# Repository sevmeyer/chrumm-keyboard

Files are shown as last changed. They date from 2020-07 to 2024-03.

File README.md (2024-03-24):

Chrumm keyboard
===============

Chrumm is an open-hardware ergonomic keyboard,
made of a 3D-printable body, a bendable PCB,
and custom firmware for the Raspberry Pi Pico.

This repository contains all relevant source files.
I share these files in the hope that they are useful, or
at least interesting to others. Keep in mind that this is
a free, do-it-yourself project. What you see is what you get.
Make sure to check the license.

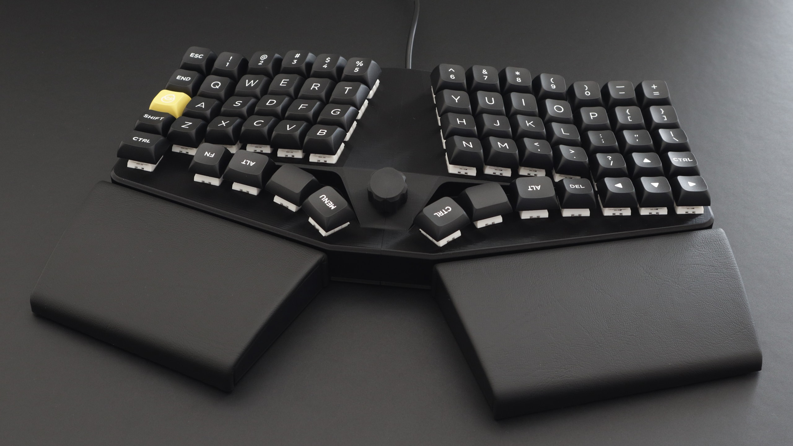
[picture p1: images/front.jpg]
Front view of the finished keyboard


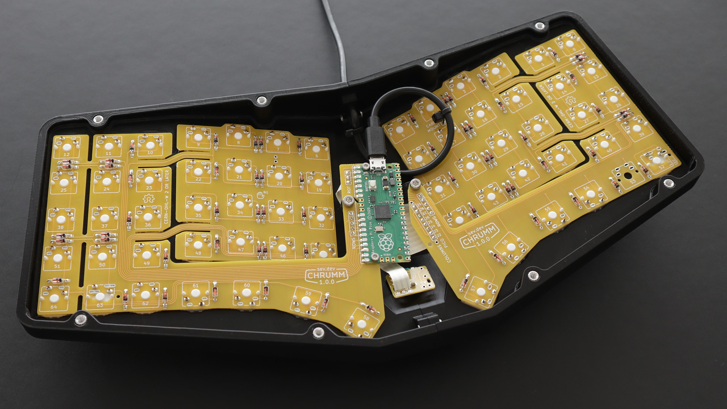
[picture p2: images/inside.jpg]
Inside view with installed electronics


Files
-----

- [Releases] - Download page for STL, 3MF, GBR, UF2 files
- [BUILD.md](BUILD.md) - Build advice
- [MATERIALS.md](MATERIALS.md) - Bill Of Materials
- [pcb/README.md](pcb/README.md) - PCB production details
- [body/README.md](body/README.md) - Body generator parameters
- [firmware/README.md](firmware/README.md) - Firmware overview and installation

[Releases]: https://github.com/sevmeyer/chrumm-keyboard/releases/

Features
--------

Chrumm features a column staggered layout with simple thumb clusters.
The right side has an additional column, to better approximate
the standard ANSI layout, and to provide dedicated arrow keys.
A central encoder allows for rotational input.

The body is a robust monoblock without visible screws. It has
integrated split, tent, and tilt angles, similar to commercial
ergonomic boards. The palm rests and the USB cable are firmly
attached, so that everything can be moved around without hassle.

The STL files are generated programmatically, with a pure
Python package that has no dependencies. They are optimized
for FFF 3D printing. Most parts are printed sideways, to
produce a smooth surface without the need of post-processing.
Custom supports minimize the print time and filament cost.

The body houses two reversible, bendable, interconnected PCBs.
They are powered by a Raspberry Pi Pico.

Layout
------

Default logical layout with two layers

Credit
------

Chrumm would not exist without the shared knowledge of the
mechanical keyboard community.

I found inspiration on [Reddit], [KBD.news], [geekhack], and
learned a lot from the [PCB guides] by ai03 and Ruiqi Mao, the
[Keyboard posts] by Masterzen, and the [Matrix Help] by Dave Dribin.

The layout and body is influenced by projects like the [Ergodox],
[Dactyl], [Sofle], [Pteron], and everything from [Bastardkb].
I also used established open hardware repositories for reference,
including the [UHK60], [Skeletyl], [Sofle], [Corne], and [Torn].

[Reddit]: https://old.reddit.com/r/ErgoMechKeyboards+MechanicalKeyboards/
[KBD.news]: https://kbd.news/
[geekhack]: https://geekhack.org
[PCB guides]: https://wiki.ai03.com/books/pcb-design
[Keyboard posts]: https://www.masterzen.fr/tag/#mechanical-keyboards
[Matrix Help]: https://www.dribin.org/dave/keyboard/one_html/
[Ergodox]: https://www.ergodox.io/
[Dactyl]: https://github.com/adereth/dactyl-keyboard
[Sofle]: https://github.com/josefadamcik/SofleKeyboard
[Pteron]: https://github.com/FSund/pteron-keyboard
[Bastardkb]: https://bastardkb.com/
[UHK60]: https://github.com/UltimateHackingKeyboard/uhk60v1-electronics
[Skeletyl]: https://github.com/Bastardkb/Skeletyl-PCB-plate
[Corne]: https://github.com/foostan/crkbd
[Torn]: https://github.com/rtitmuss/torn

Gallery
-------

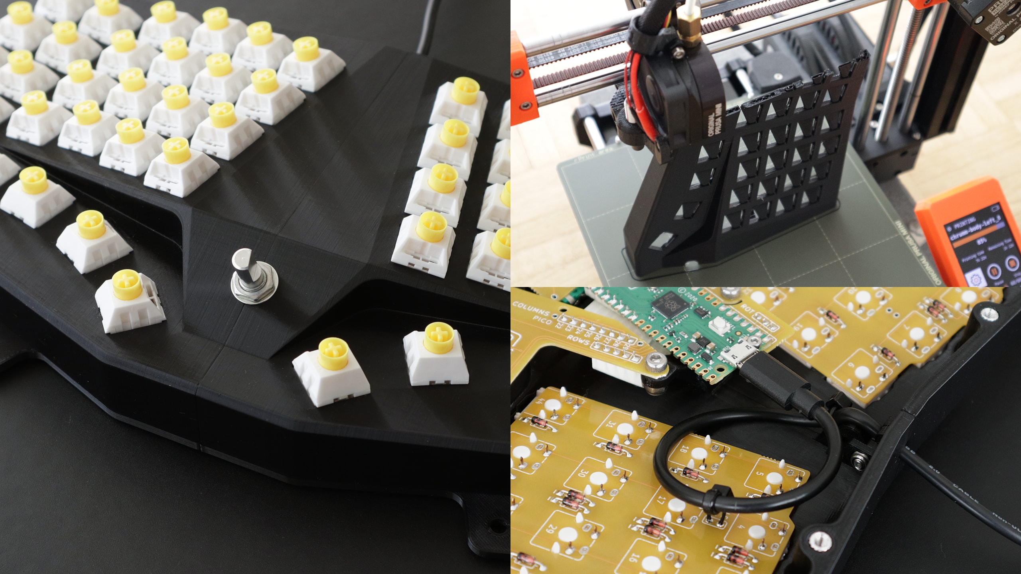
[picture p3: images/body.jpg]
Print and assembly of the body


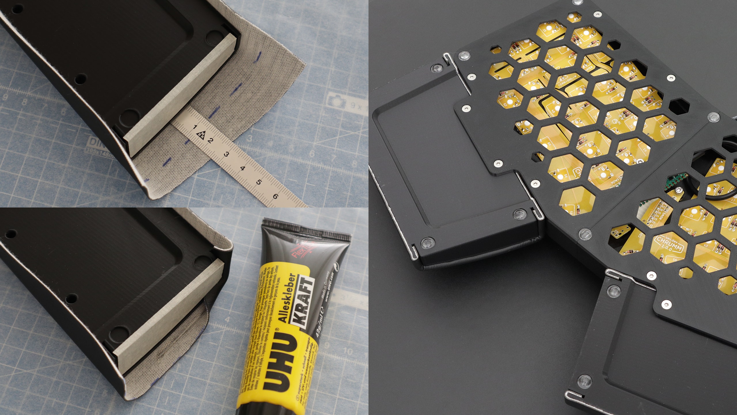
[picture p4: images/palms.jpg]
Palm rests wrapped with artificial leather


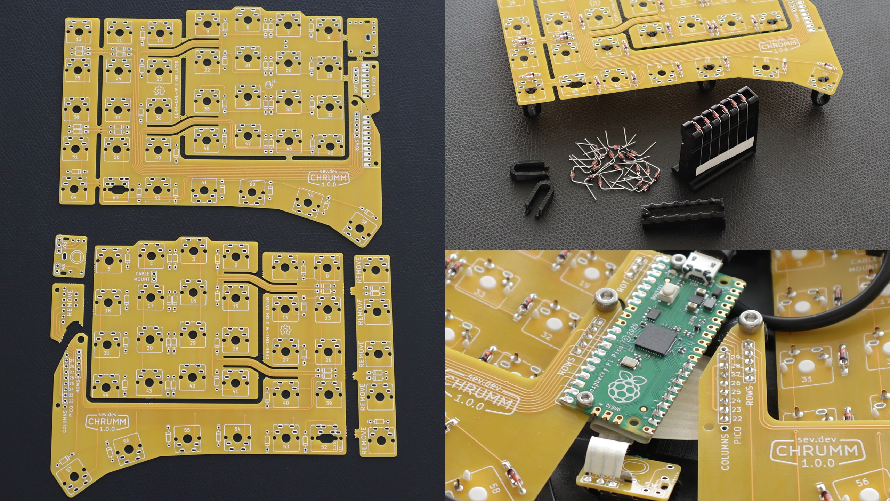
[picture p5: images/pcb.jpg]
Preparation and installation of the PCB


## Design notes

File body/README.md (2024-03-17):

Chrumm STL generator
====================

The STL files are generated with the `chrumm` package for Python 3.7+.
It has no dependencies and does not need to be compiled or installed.
Run it as a command-line tool from this directory:

    python3 -m chrumm --help

To generate the default STL files:

    python3 -m chrumm chrumm.json

Parameters
----------

The configuration parameters are provided via JSON files.
If a parameter appears multiple times, then its latest value
is used. Distances are given in millimeters, angles in degrees.

#### PCB compatibility

Unlike the body, the PCB is manually edited and not programmatic.
Changes to the body parameters may not be compatible with the PCB.
A flattened KiCad footprint (.kicad_mod) is generated to help with
the placement of the switches and screws on the PCB.

#### Parameter validation

The generator does not validate all of the parameters.
Most importantly, chamfers and switch notches are not
taken into account when placing the walls. Make sure
that the switch margin parameter provides enough room.

The generator should produce reasonable results for
split, tent, and tilt angles up to about 20 degrees.
Results may vary for more extreme angles.

#### Layout

The `layout.fingerStaggers` matrix represents the
offset of each key relative to its ortholinear position.

The matrix is a list of rows. Each row contains four
sublists, to represent the sections of the keyboard
(left pinky, left alnum, right alnum, right pinky).
Each section contains key offset coordinates.
A coordinate can be an empty list (key omitted), a single
number (y offset), or a list of two numbers (x and y offset).

Each section must have at least two key coordinates.
All rows must have the same column structure.

#### Omit items

Chamfers can be turned off by setting them to `0`.
The value of the following parameters can be set
to `false` in order to omit them from the output:

    bracket
    bumper
    cable
    encoder
    floor.hexHoles
    knob
    palm
    pcb
    pcb.mount
    support
    switch.clipNotch

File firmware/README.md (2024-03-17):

Chrumm firmware
===============

The firmware is written in C for the [Raspberry Pi Pico].
If you instead prefer a more standard toolkit, check out
the experimental [QMK config] for Chrumm.

[Raspberry Pi Pico]: https://www.raspberrypi.com/products/raspberry-pi-pico/
[QMK config]: https://github.com/sevmeyer/chrumm-qmk

Features
--------

The firmware implements two [USB HID] interfaces. Interface 0 acts
as a standard Boot Keyboard. Interface 1 sends HID Consumer codes
for application-specific controls, including multimedia.

Two layers are available. Hold down the `Fn` key to momentarily
activate the alternative layer. Double tap `Fn` to stay on the
alternative layer until `Fn` is tapped again.

Optionally, the rotation signals of an EC11 encoder can be
mapped to virtual key presses.

The special `kBOOT` keycode (Fn+Z) can be tapped three times
to put the keyboard into bootloader mode without the need to
unplug the USB cable.

For debugging purposes, the on-board LED of the Pico indicates
non-default lock states. When Caps Lock is on, the LED is on.
When Num Lock is off, the LED blinks once every 2 seconds.

[USB HID]: https://www.usb.org/document-library/device-class-definition-hid-111

Compile
-------

The default UF2 binary is available on the [Releases] page.

To compile a custom version, install the [Pico SDK] and [Arm GNU Toolchain].
Set the `PICO_SDK_PATH` environment variable to the SDK directory.
Append the Arm `bin` directory to the `PATH` environment variable.
The firmware can then be prepared and compiled with:

    cmake -B build
    cmake --build build

[Releases]: https://github.com/sevmeyer/chrumm-keyboard/releases
[Pico SDK]: https://github.com/raspberrypi/pico-sdk
[Arm GNU Toolchain]: https://developer.arm.com/Tools%20and%20Software/GNU%20Toolchain

Install
-------

Hold down the `BOOTSEL` button on the Pico while plugging in
the USB cable. It should show up as a USB storage device.
After the first install, you can keep the keyboard plugged in
and instead tap Fn+Z three times.

Drag-and-drop the UF2 binary from the build directory onto the device.
The Pico should automatically restart and run the firmware.
Alternatively, install [picotool] and use:

    picotool load build/chrumm.uf2 --force
    picotool reboot

[picotool]: https://github.com/raspberrypi/picotool

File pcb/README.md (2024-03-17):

Chrumm PCB
==========

The PCB is made with [KiCad], version 7.

The PCB is reversible. It covers half of the keyboard,
and is flipped over for the other half. It is intended
to slightly bend between the pinky and ring finger,
therefore the board thickness should not exceed 0.8mm.

All connections are through-hole (or castelated), so
that they can be soldered with basic hobby equipment.
The switch pin holes are implemented as slots, to
provide a snug fit for the flat pins, and thus
minimize the required amount of solder.

[KiCad]: https://www.kicad.org/

Teardrops
---------

The teardrops are generated with a custom [KiCad plugin],
using the following settings:

    PTH arc radius: 250%
    SMD arc radius: 250%
    Via arc radius: 350%

[KiCad plugin]: https://github.com/sevmeyer/kicad-arc-teardrops

Production
----------

I ordered the prototypes from [PCBWay] (no affiliation).
Other manufacturers are available, check for example
[PCBShopper] or [Manufacturing Reports]. Here are some of
the relevant specifications, use them at your own discretion:

- Standard PCB (not flex)
- Single pieces (not panelized)
- Layers: 2
- Material: FR4 TG 150-160
- Thickness: 0.8mm (at most)
- Surface finish: HASL (lead free)
- Copper thickness: 1oz

[PCBWay]: https://pcbway.com/
[PCBShopper]: https://pcbshopper.com/
[Manufacturing Reports]: https://manufacturingreports.com/category/electronics/rigid-pcb-fabrication/

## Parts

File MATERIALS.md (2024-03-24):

Chrumm Bill Of Materials
========================

Mechanical
----------

- 12x Threaded insert, M3, 4mm hole diameter, max 5.7mm length
- 12x Countersunk screw, M3, 8mm total length, ISO 10642
-  7x Hex nut with nylon insert, M3, ISO 10511
-  2x Hex nut with nylon insert, M2
-  7x Socket head cap screw, M3, 8mm thread length, ISO 4762 (*)
-  2x Socket head cap screw, M2, 6mm thread length, ISO 4762
-  2x Ziptie, 2mm width, 1mm thickness
- 14x 3M Bumpon SJ5302, hemispherical, 8mm diameter, 2mm height
-  2x Artificial leather, ~190x130mm, max 1.2mm thickness
- Glue for artificial leather on printed filament
- Keycaps (in photo: Akko WOB Building Blocks, MDA profile)

(*) Some of the screws are difficult to reach and
require a ball-point driver, or a short-armed key.

Electronic
----------

-  2x PCB
-  1x Raspberry Pi Pico, SC0915, without pre-soldered headers
-  1x USB cable, A to micro-B with small head, shielded, max 4mm diameter
- 64x Diode, 1N4148, DO-35 through-hole format
- 64x MX switch
-  1x Bourns PEC11R-4215F-N0024 rotary encoder, M7 nut mount, 15mm flatted D-shaft
-  1x TE Flexstrip FSN-22A-8, 0.1" pitch, 2" length, 8 conductors (**)
-  1x TE Flexstrip FSN-22A-5, 0.1" pitch, 2" length, 5 conductors (**)
-  1x TE Flexstrip FSN-23A-3, 0.1" pitch, 3" length, 3 conductors (**)

(**) It might be cheaper to buy strips with
more conductors and cut them apart as needed.

3D-printed
----------

-  2x Body half (left, right)
-  2x Floor half (left, right)
-  2x Palm rest (left, right)
-  1x Rotary encoder knob
-  1x Diode bender jig, 7.62mm pitch (300mil)
- 12x Diode standoff jig

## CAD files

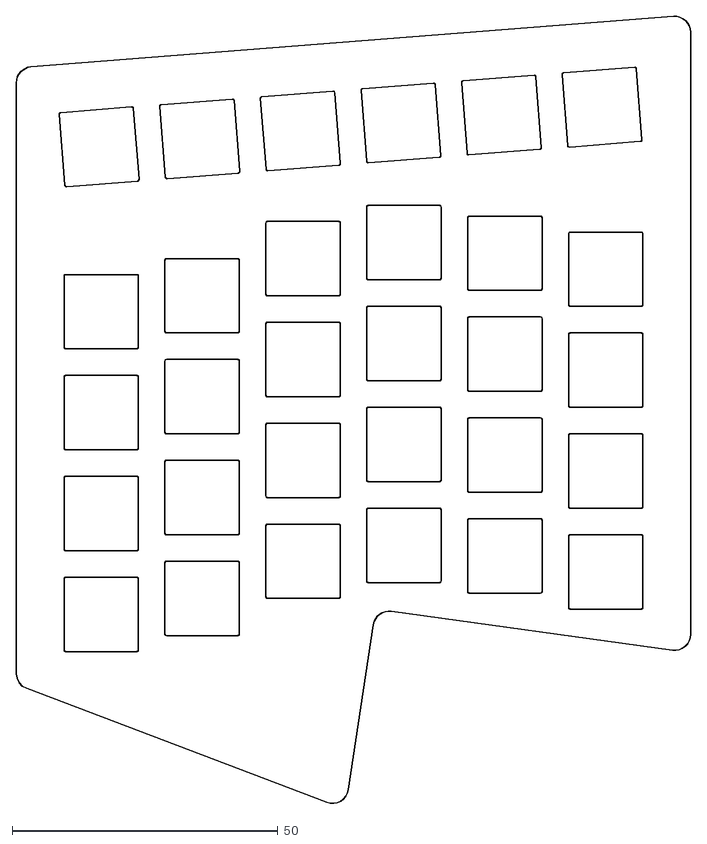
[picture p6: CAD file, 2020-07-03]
files/chrumm-01-plate-left.dxf
127.0 x 148.4

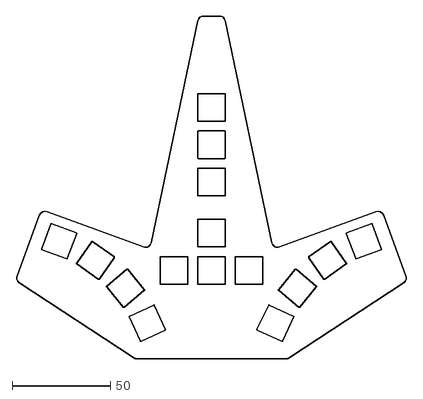
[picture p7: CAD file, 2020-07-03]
files/chrumm-01-plate-middle.dxf
198.9 x 174.5

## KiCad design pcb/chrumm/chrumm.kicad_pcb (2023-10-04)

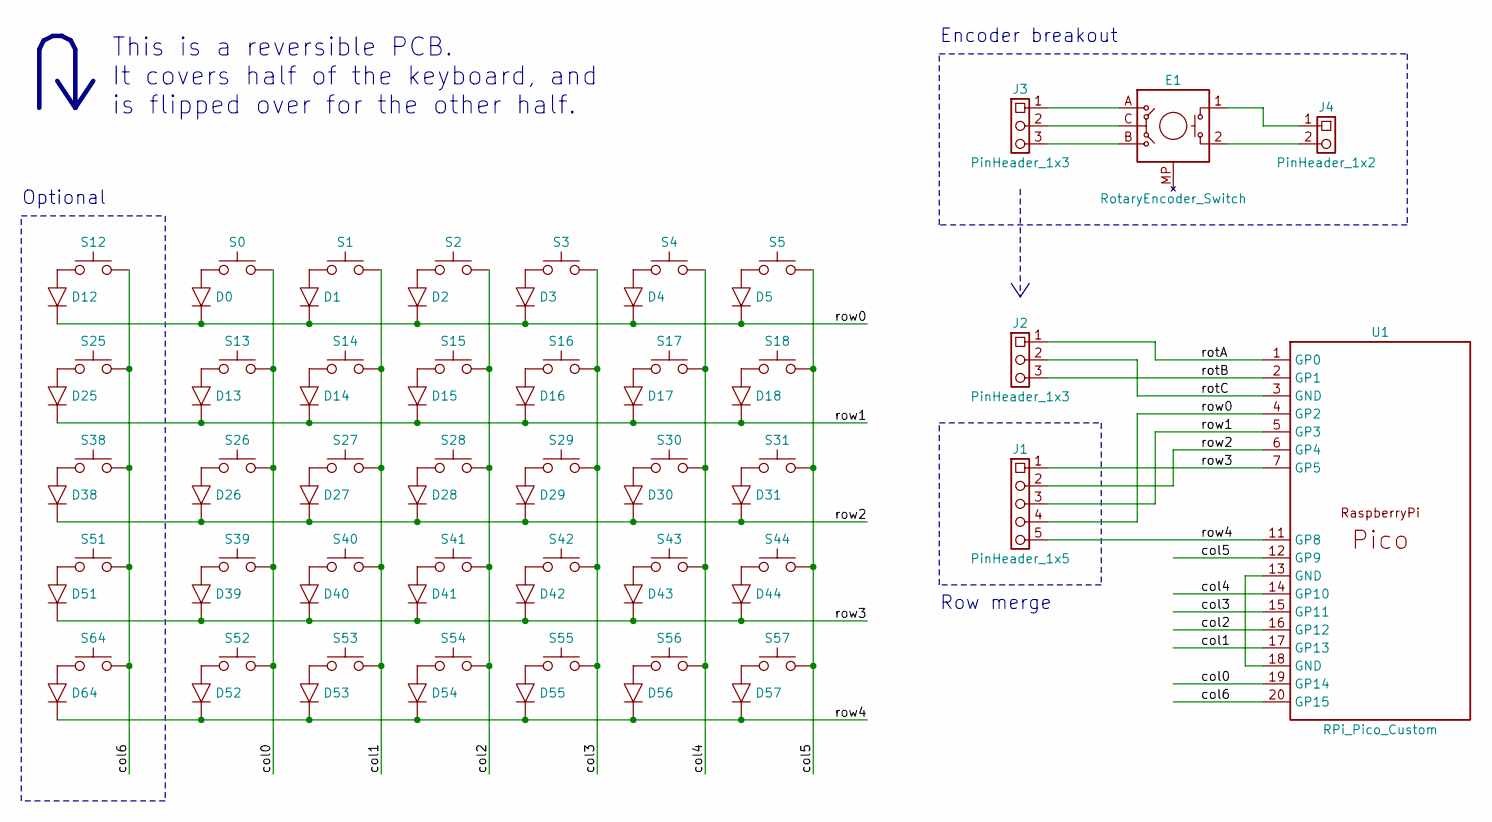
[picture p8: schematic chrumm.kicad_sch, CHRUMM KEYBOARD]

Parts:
D0, D1, D2, D3, D4, D5, D12, D13, D14, D15, D16, D17, D18, D25, D26, D27, D28, D29, D30, D31, D38, D39, D40, D41, D42, D43, D44, D51, D52, D53, D54, D55, D56, D57, D64: Diode
E1: RotaryEncoder_Switch
J1: PinHeader_1x5
J2, J3: PinHeader_1x3
J4: PinHeader_1x2
S0, S1, S2, S3, S4, S5, S12, S13, S14, S15, S16, S17, S18, S25, S26, S27, S28, S29, S30, S31, S38, S39, S40, S41, S42, S43, S44, S51, S52, S53, S54, S55, S56, S57, S64: Switch
U1: RPi_Pico_Custom

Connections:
/col0: S0.1, S13.1, S26.1, S39.1, S52.1, U1.19 (GP14)
/col1: S1.1, S14.1, S27.1, S40.1, S53.1, U1.17 (GP13)
/col2: S2.1, S15.1, S28.1, S41.1, S54.1, U1.16 (GP12)
/col3: S3.1, S16.1, S29.1, S42.1, S55.1, U1.15 (GP11)
/col4: S4.1, S17.1, S30.1, S43.1, S56.1, U1.14 (GP10)
/col5: S5.1, S18.1, S31.1, S44.1, S57.1, U1.12 (GP9)
/col6: S12.1, S25.1, S38.1, S51.1, S64.1, U1.20 (GP15)
/rotA: J2.1, U1.1 (GP0)
/rotB: J2.3, U1.2 (GP1)
/rotC: J2.2, U1.3 (GND)
/row0: D0.1 (K), D1.1 (K), D2.1 (K), D3.1 (K), D4.1 (K), D5.1 (K), D12.1 (K), J1.4, U1.4 (GP2)
/row1: D13.1 (K), D14.1 (K), D15.1 (K), D16.1 (K), D17.1 (K), D18.1 (K), D25.1 (K), J1.3, U1.5 (GP3)
/row2: D26.1 (K), D27.1 (K), D28.1 (K), D29.1 (K), D30.1 (K), D31.1 (K), D38.1 (K), J1.2, U1.6 (GP4)
/row3: D39.1 (K), D40.1 (K), D41.1 (K), D42.1 (K), D43.1 (K), D44.1 (K), D51.1 (K), J1.1, U1.7 (GP5)
/row4: D52.1 (K), D53.1 (K), D54.1 (K), D55.1 (K), D56.1 (K), D57.1 (K), D64.1 (K), J1.5, U1.11 (GP8)
unnamed: D0.2 (A), S0.2
unnamed: D1.2 (A), S1.2
unnamed: D2.2 (A), S2.2
unnamed: D3.2 (A), S3.2
unnamed: D4.2 (A), S4.2
unnamed: D5.2 (A), S5.2
unnamed: D12.2 (A), S12.2
unnamed: D13.2 (A), S13.2
unnamed: D14.2 (A), S14.2
unnamed: D15.2 (A), S15.2
unnamed: D16.2 (A), S16.2
unnamed: D17.2 (A), S17.2
unnamed: D18.2 (A), S18.2
unnamed: D25.2 (A), S25.2
unnamed: D26.2 (A), S26.2
unnamed: D27.2 (A), S27.2
unnamed: D28.2 (A), S28.2
unnamed: D29.2 (A), S29.2
unnamed: D30.2 (A), S30.2
unnamed: D31.2 (A), S31.2
unnamed: D38.2 (A), S38.2
unnamed: D39.2 (A), S39.2
unnamed: D40.2 (A), S40.2
unnamed: D41.2 (A), S41.2
unnamed: D42.2 (A), S42.2
unnamed: D43.2 (A), S43.2
unnamed: D44.2 (A), S44.2
unnamed: D51.2 (A), S51.2
unnamed: D52.2 (A), S52.2
unnamed: D53.2 (A), S53.2
unnamed: D54.2 (A), S54.2
unnamed: D55.2 (A), S55.2
unnamed: D56.2 (A), S56.2
unnamed: D57.2 (A), S57.2
unnamed: D64.2 (A), S64.2
unnamed: E1.1, J4.1
unnamed: E1.2, J4.2
unnamed: E1.A, J3.1
unnamed: E1.B, J3.3
unnamed: E1.C, J3.2
unnamed: U1.13 (GND), U1.18 (GND)

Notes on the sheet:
Encoder breakout
Optional
Row merge
This is a reversible PCB. It covers half of the keyboard, and is flipped over for the other half.

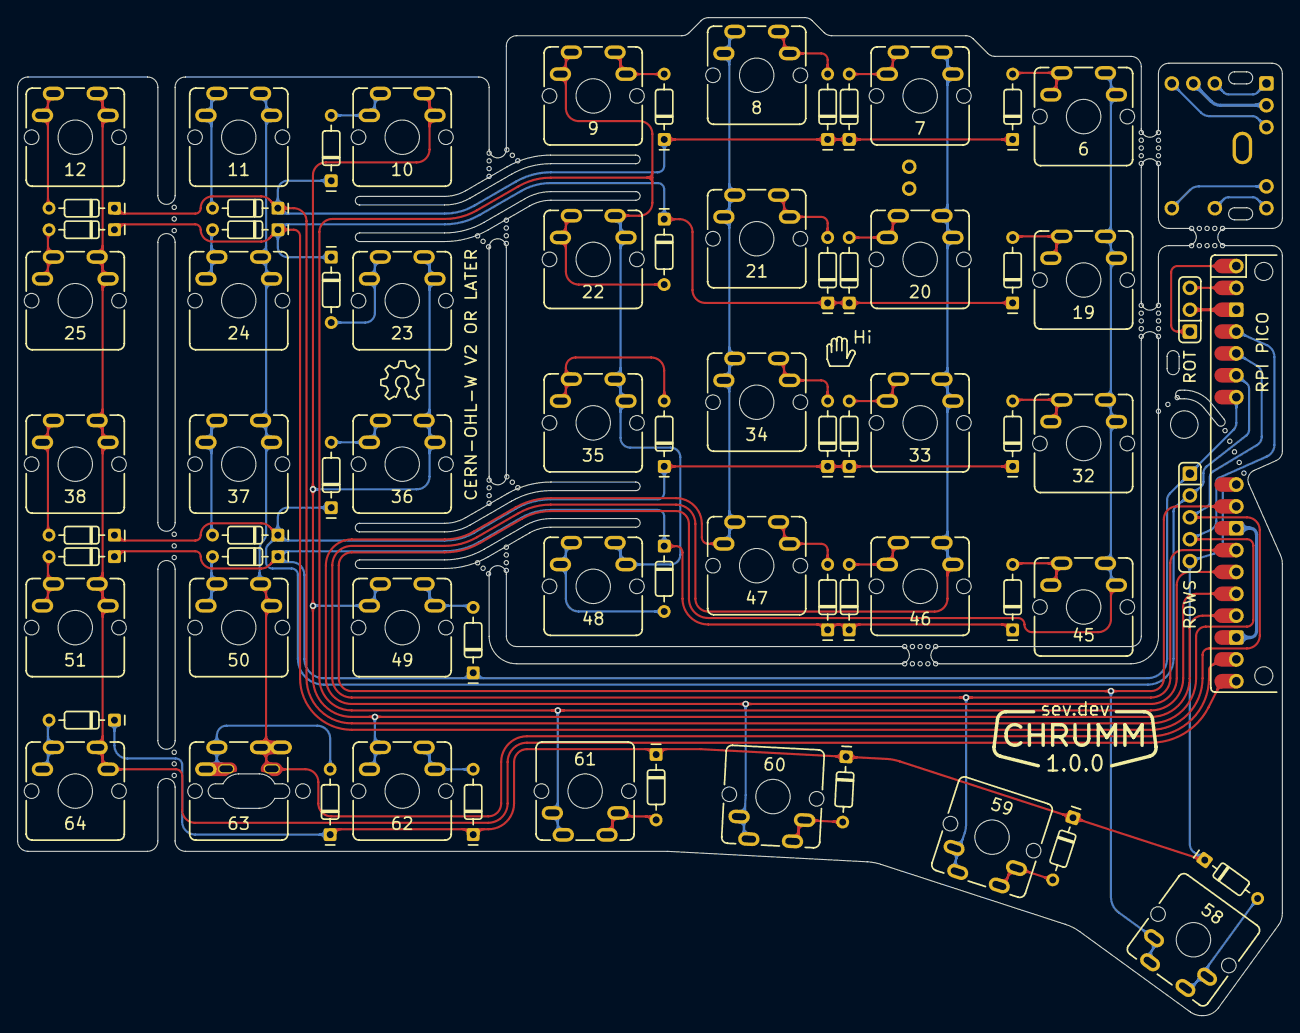
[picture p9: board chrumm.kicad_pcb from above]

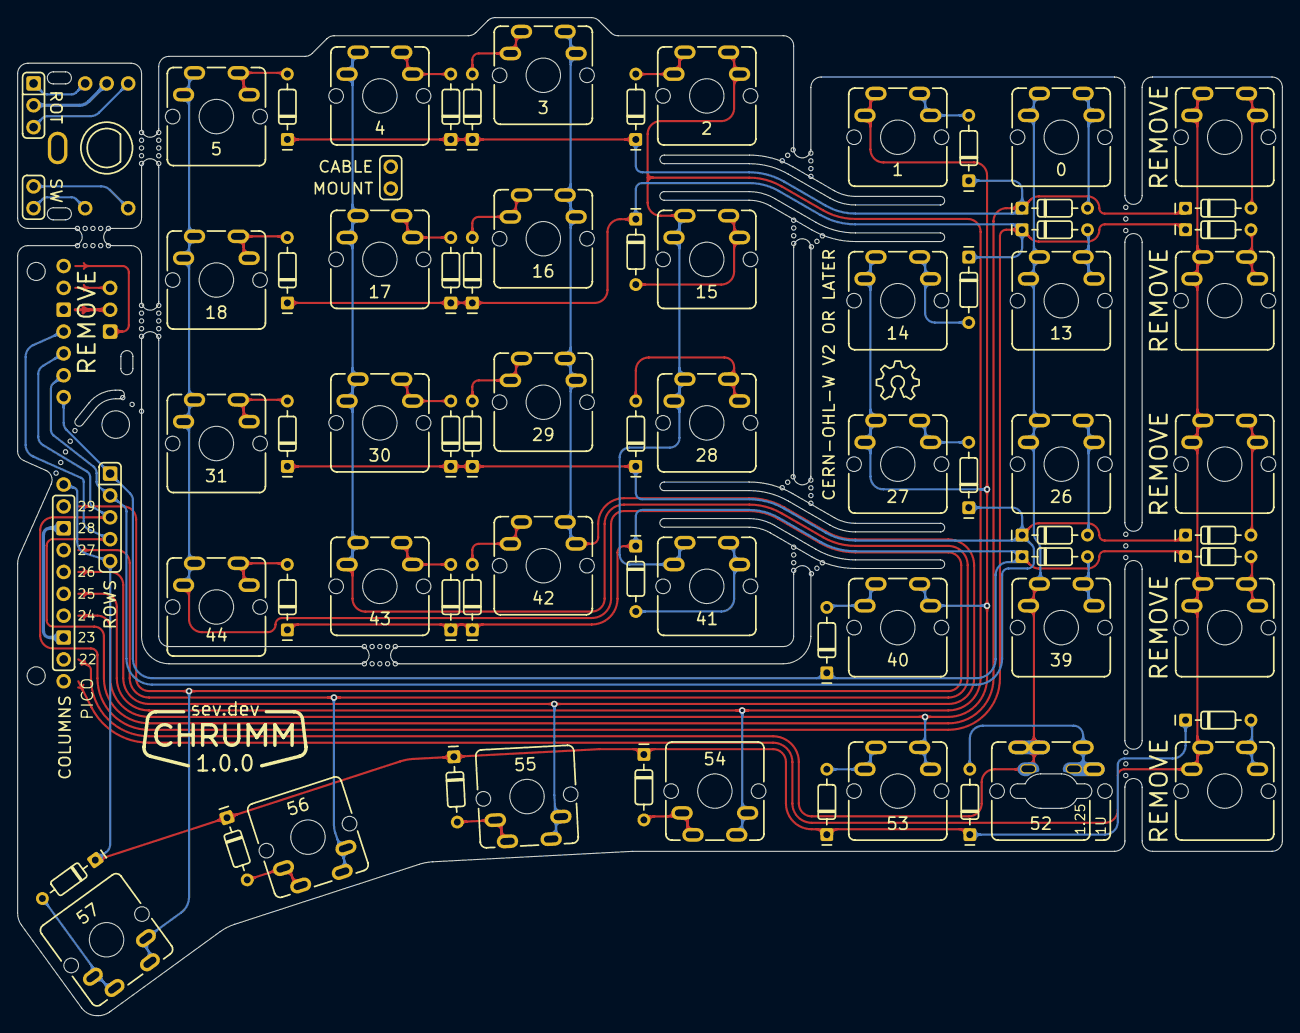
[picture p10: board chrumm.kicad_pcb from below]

Board: 2 copper layers, 147.0 x 116.0 mm, 76 parts (9 on the bottom side), 56 nets.

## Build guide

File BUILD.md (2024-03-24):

Chrumm build advice
===================

Printing
--------

I printed the parts on a Prusa Mini, with PLA filament, on a
smooth PEI sheet. The gcode was generated with [PrusaSlicer] 2.6.0.
The 3MF files with the exact print settings and part configurations
are available on the [Releases] page.

The body halves are printed sideways, with custom supports.
In PrusaSlicer, custom supports can be added in the
[Object list] (Advanced mode). Right-click on the body object
and load the support STL with "Add Part". Right-click on the
support object to adjust its print settings.

[PrusaSlicer]: https://www.prusa3d.com/prusaslicer/
[Object list]: https://help.prusa3d.com/article/object-list_1758
[Releases]: https://github.com/sevmeyer/chrumm-keyboard/releases

Diodes
------

Note that there is not much room between the switch plate and
the PCB. Therefore, I soldered the diode legs on the same side
as the diode body, and cut the legs reasonably short on the
switch-facing side with a [flush cutter]. To hold up the PCB
while soldering the diodes, I used standoff jigs that clip
into the stem holes (see photos).

The diode pads have a common pitch of 7.62mm (300mil).
To bend the legs in a uniform way, I used a bender jig.
Both jigs are available on the [Releases] page.

[flush cutter]: https://en.wikipedia.org/wiki/Diagonal_pliers#Variations

Flexstrip
---------

The PCB halves are connected via Flexstrip jumpers. To compensate
for the default split angle, the strips should be folded in a
specific way before installation. Check the image for reference.
I wrapped the strips around a thin screwdriver shaft, to maintain
a minimum bend radius of about 2mm.

Fold lines for flexstrip jumpers

PCB installation
----------------

To install the PCB, I would first clip the corner switches
into the body, e.g. switches 12-64-58, 10-9-6, and 49-48-45.
Then align the PCB with the switch pins and push it flat
against the switch bottoms.

Before soldering any switches, check that the screw mount
next to the Pico does not bend the PCB. If the print is
misaligned, you might want to sand off a bit of the mount,
or extend its height with a washer.

When everything fits, the remaining switches can be inserted.
Note that the thumb switches are north-facing (upside down).

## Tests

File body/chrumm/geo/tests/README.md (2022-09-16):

Run the tests from the parent directory of the chrumm package:

    python3 -m unittest discover

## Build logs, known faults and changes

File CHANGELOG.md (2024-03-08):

Development
-----------

body 1.0.2
- Add optional parameters for switches with clips on their side
  * switch.clipNotch.isSideways  (Left-right instead of front-back)
  * support.relBasePosition      (Sideways position relative to top)
  * support.relBaseInset         (From switch hole front to back)
  * support.relTopInset          (From switch hole front to back)

body 1.0.1
- Revise Face triangulation for better performance
- Remove obsolete draft.json

firmware 1.0.2
- Use PID 1209:5E7C as registered on pid.codes

firmware 1.0.1
- Add kBOOT keycode to trigger bootloader mode
- Remove cRWND and cFFWD from default layout
- Revise pin settle time and encoder keypress ticks

1.0 (2023-10-04)
----------------

- First release

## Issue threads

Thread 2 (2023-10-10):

Chrumm 36

sahidrahman404, 2023-10-10:
Are there any plans to create a variant of this keyboard with 36 keys?

sevmeyer, 2023-10-10:
I assume you refer to Miryoku. There are no plans to support such small layouts, sorry.

The current construction of the body and PCB assumes at least two pinky columns.
Also, the Pico would not easily fit in its current orientation.
Ultimately, Miryoku would require non-trivial adjustments.

Closed 2023-10-10.

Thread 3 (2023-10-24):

stls

TuneClausen, 2023-10-24:
Hello. I'm in love with the chrumm and have today recieved the pcbs. Could you upload the stls that you have used for your layout? I fear that I'm too stupid to use the python files that you have supplied :)

giovanniborella, 2023-10-24:
Check the releases: https://github.com/sevmeyer/chrumm-keyboard/releases/tag/1.0

sevmeyer, 2023-10-24:
Thanks @giovanniborella.

On the releases page you can also download the 3mf files,
which contain the print settings for [PrusaSlicer] 2.6.

[PrusaSlicer]: https://www.prusa3d.com/page/prusaslicer_424/

Closed 2023-10-24.

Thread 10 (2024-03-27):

Request: add space for trackpoint module

btittelbach, 2024-03-27:
Hi,

## Feature Request
I would be awesome if you could add an optional feature for the body stl generator, so people can more easily duplicate my modification of Chrumm in which I  added a trackpoint module in the middle.

Earlier you said you wanted Chrumm to be a portifolio project and prefer to write your own code, so I though it would be better to open an issue rather than modify the nice STL generator code and then have an unaccepted pull-request.

## Rationale
I found that the space in the middle of chrumm, lends itself perfectly to add a trackpoint module. Even more so, if the split is increased to something more ergonomic. (I used 20° split, which may even be a bit too much, but comes close to my ideal)

Having a mouse pointer integrated with the keyboard, reduces the need to move the hands away from the keyboard position.

The FN-Layer can be used for mouse buttons.
If someone is interested in my QMK configuration that drives the trackpoint, it can be found [here](https://github.com/btittelbach/chrumm-qmk/tree/main/chrumm/keymaps/btittelbach_65keys_mouse)

## Specs

The Trackpoint Module has the following dimensions:
width: 28,7mm
length: 31,2mm
height: 0,7mm höhe

Ideally the the generator would add a small indentation for the module as well as a hole for the cable and a wedge to get the cables to the hole as well as a small circular pit below the trackpoint nub to accomodate the rivets.

Below the trackpoint nub, a circular indentation with additional height of 0,5mm and diameter of 14mm would be needed to accommodate the rivets seen on the photo. Unfortunately I forgot to add those to my design. The circle center should be 1,3mm from the edge in width-axis and 0,6mm from the edge in length-axis. (the smaller edge-center distances were measured.

The pin-header of the trackpoint module is 14,5mm in width and centered with 7,5mm distance from the edge on both sides on the width-axis. Though the 3 pins on the left side are for mouse buttons and are not needed. Pin-pitch is about 1,72mm.

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

sevmeyer, 2024-03-28:
It is really neat that you are making use of Chrumm and come up with new ideas.

However, after years of development and refinement, my work on Chrumm is done.
I do not intend to add new features, especially if I have not physically tested them myself.

I apologize for not communicating this more clearly in the repository.

Of course, you are welcome to maintain your own fork, as many people have done with the Dactyl for example.

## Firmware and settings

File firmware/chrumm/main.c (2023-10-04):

// Chrumm keyboard firmware
//   ___ _   _ ____  _   _ __  __ __  __
// .' __| |_| |  _ '| | | |  \/  |  \/  |
// | |__|  _  | |_) | |_| | |\/| | |\/| |
// '.___|_| |_|_| \_\.___.|_|  |_|_|  |_|
//
// Copyright 2023 Severin Meyer
// Licensed under CERN-OHL-W v2 or later

#include "chrumm/config.h"
#include "chrumm/encoder.h"
#include "chrumm/hid.h"
#include "chrumm/led.h"
#include "chrumm/matrix.h"

#include <tusb.h>
#include <hardware/clocks.h>
#include <hardware/watchdog.h>
#include <pico/stdlib.h>


int main()
{
    set_sys_clock_48mhz();
    clock_stop(clk_peri);
    clock_stop(clk_adc);
    clock_stop(clk_rtc);

    matrix_init();
    encoder_init();
    led_init();
    tud_init(0);

    watchdog_enable(WATCHDOG_TIMEOUT_MS, false);

    while (true) {
        absolute_time_t timeout = make_timeout_time_us(TICK_INTERVAL_US);

        matrix_tick();
        encoder_tick();
        hid_tick();
        led_tick();
        tud_task();
        watchdog_update();

        sleep_until(timeout);
    }
}

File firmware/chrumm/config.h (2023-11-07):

#pragma once

#include "chrumm/usage.h"


// GPIO pins
// ---------

#define MATRIX_ROWS  5
#define MATRIX_COLS  13

#define MATRIX_ROW_PINS  { 2, 3, 4, 5, 8 }
#define MATRIX_COL_PINS  { 17, 18, 19, 20, 21, 22, 9, 10, 11, 12, 13, 14, 15 }

#define ENCODER_A_PIN  0
#define ENCODER_B_PIN  1

#define LED_PIN  25


// HID usage
// ---------

#define MATRIX_BASE_LAYER  {\
    kESC,   k1,     k2,     k3,     k4,     k5,     k6,     k7,     k8,     k9,     k0,     kMINUS, kEQUAL, \
    kTAB,   kQ,     kW,     kE,     kR,     kT,     kY,     kU,     kI,     kO,     kP,     kLBRAC, kRBRAC, \
    cFN,    kA,     kS,     kD,     kF,     kG,     kH,     kJ,     kK,     kL,     kCOLON, kQUOTE, kBKSL,  \
    kLSHFT, kZ,     kX,     kC,     kV,     kB,     kN,     kM,     kCOMMA, kDOT,   kSLASH, kUP,    kRSHFT, \
    kLCTRL, kNONE,  kLGUI,  kLALT,  kSPACE, kBKSP,  kENTER, kSPACE, kRALT,  kDEL,   kLEFT,  kDOWN,  kRIGHT  }

#define MATRIX_FN_LAYER  {\
    kTILDE, kF7,    kF8,    kF9,    kF10,   kF11,   kF12,   kp7,    kp8,    kp9,    kpSUB,  kBKSP,  kESC,   \
    kCAPLK, kF1,    kF2,    kF3,    kF4,    kF5,    kF6,    kp4,    kp5,    kp6,    kpADD,  kpLPAR, kpRPAR, \
    cFN,    cPLAY,  cPREV,  cPAUSE, cNEXT,  cSTOP,  kNONE,  kp1,    kp2,    kp3,    kpDIV,  kNONE,  kNONE,  \
    kLSHFT, kBOOT,  kNONE,  cCALC,  kNONE,  kMUTE,  kNUMLK, kp0,    kpDOT,  kpENT,  kpMUL,  kPGUP,  kRSHFT, \
    kLCTRL, kNONE,  kLGUI,  kLALT,  kSPACE, kBKSP,  kENTER, kSPACE, kRALT,  kINS,   kHOME,  kPGDN,  kEND    }

#define ENCODER_CW_USAGE   kVOLUP
#define ENCODER_CCW_USAGE  kVOLDN


// Timing
// ------

#define WATCHDOG_TIMEOUT_MS  100
#define PIN_SETTLE_TIME_US   10
#define TICK_INTERVAL_US     500

#define MATRIX_DEBOUNCE_TICKS   8
#define ENCODER_KEYPRESS_TICKS  30
#define LED_BLINK_TICKS         500

#define FN_KEY_TAPS    2
#define BOOT_KEY_TAPS  3

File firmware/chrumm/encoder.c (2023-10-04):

#include "chrumm/encoder.h"
#include "chrumm/config.h"
#include "chrumm/hid.h"
#include "chrumm/usage.h"
#include <pico/stdlib.h>


#if defined(ENCODER_A_PIN) && defined(ENCODER_B_PIN)

static void report(uint32_t usage);


void encoder_init()
{
    gpio_init(ENCODER_A_PIN);
    gpio_set_dir(ENCODER_A_PIN, GPIO_IN);
    gpio_pull_up(ENCODER_A_PIN);

    gpio_init(ENCODER_B_PIN);
    gpio_set_dir(ENCODER_B_PIN, GPIO_IN);
    gpio_pull_up(ENCODER_B_PIN);
}


void encoder_tick()
{
    // The signal is decoded with a simple state machine,
    // using a lookup table to determine the next state.
    // Rotation events are only reported if the signal goes
    // through the correct sequence of states. This filters out
    // contact bounces, without the need for extra hardware.
    //
    // EC11 quadrature signal
    //
    // _|_  |   |  _|___ A pin
    //  | \_|___|_/ |
    // _|___|_  |   |  _ B pin
    //  |   | \_|___|_/
    // 11  01  00  10    AB
    //
    // Signal state machine
    //
    // .---. <-01.---. <-00.---. <-10.---.01-> .---.00-> .---.10-> .---.
    // |001|     |000|     |010|     |   |     |101|     |100|     |110|
    // '---'00-> '---'10-> '---'11-> |011| <-11'---' <-01'---' <-00'---'
    // 11                            |   |                            11
    // '-------------CCW EVENT-----> '---' <-----CW EVENT--------------'

    static const uint8_t next[28] = {
        0b000, 0b001, 0b010, 0b000,  // 000AB
        0b000, 0b001, 0b001, 0b011,  // 001AB
        0b000, 0b010, 0b010, 0b011,  // 010AB
        0b011, 0b101, 0b010, 0b011,  // 011AB
        0b100, 0b101, 0b110, 0b100,  // 100AB
        0b100, 0b101, 0b101, 0b011,  // 101AB
        0b100, 0b110, 0b110, 0b011}; // 110AB

    static uint8_t state = 0b011;
    state = state<<1 | gpio_get(ENCODER_A_PIN);
    state = state<<1 | gpio_get(ENCODER_B_PIN);

    switch (state) {
        case 0b00111: report(ENCODER_CCW_USAGE); break;
        case 0b11011: report(ENCODER_CW_USAGE);  break;
        default:      report(kNONE);             break;
    }

    state = next[state];
}


static void report(uint32_t usage)
{
    static uint32_t current = kNONE;
    static uint32_t timeout = 0;

    if (timeout)
        --timeout;
    else {
        if (current != kNONE) {
            hid_remove(current);
            current = kNONE;
        }
        if (usage != kNONE) {
            hid_add(usage);
            current = usage;
            timeout = ENCODER_KEYPRESS_TICKS;
        }
    }
}

#else

void encoder_init() {}
void encoder_tick() {}

#endif

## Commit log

2020-10-13 Update files to version 0.2
    [chrumm-01-body.stl, chrumm-01-palms.stl, chrumm-01-plate-bridged.dxf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]
2022-09-16 Update to version 0.3.0
    [chrumm-02-body.stl, chrumm-02-palms.stl, chrumm-02-plate-bridged.dxf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]
2023-10-04 Release version 1.0
    [chrumm.kicad_pcb, chrumm.kicad_sch]
2023-10-08 Add keycap set name and diode advice to README
2023-10-09 Add layer count to PCB order details
2023-11-07 Revise pin settle time and encoder keypress ticks
2023-11-22 Use PID 1209:5E7C as registered on pid.codes
2024-03-07 Add body parameters for switches with side clips
